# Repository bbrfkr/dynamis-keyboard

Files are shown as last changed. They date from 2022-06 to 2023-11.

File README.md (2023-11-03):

# dynamis
"dynamis" is the open-source 65% keyboard integrated with trackball.

dynamis

## concept
- upgradable
    - This keyboard can be upgraded from sandwitch mounted case to gasket mounted case.
- input only with this 
    - This keyboard is integrated with 34mm trackball, so you need only this to input!
- compact and major
    - 65% layout that is compact and major have been adopted.
- rich layout options
    - split backspace, split left and right shift, split space and iso enter are supported.

## supported key layout
supported-layout

## how to build
### Collect Parts
1. Order semi-assembled pcb by following the [gerbers](https://github.com/bbrfkr/dynamis-keyboard/tree/main/gerbers), [bom](https://github.com/bbrfkr/dynamis-keyboard/blob/main/bom.csv) and [positions](https://github.com/bbrfkr/dynamis-keyboard/blob/main/dynamis-pos.csv) files.
1. Order fr4 plate by following the [plate gerbers](https://github.com/bbrfkr/dynamis-keyboard/tree/main/plate/gerbers).
1. Order the 3d print for trackball cup by the following [stl file](https://github.com/bbrfkr/dynamis-keyboard/blob/main/trackball-cup/trackball-cup.stl) (Here, FDM print should be selected).
1. Choose case options between [sandwitch](https://github.com/bbrfkr/dynamis-keyboard/tree/main/case/sandwitch) and [3d printed](https://github.com/bbrfkr/dynamis-keyboard/tree/main/case/3dp).
1. Collect parts by following the [pcba BOM.md](https://github.com/bbrfkr/dynamis-keyboard/blob/main/BOM.md) and the each BOM.md of selected case option.

### Assemble
1. Assemble semi-assembled pcb completely by following the [pcba build guide](https://github.com/bbrfkr/dynamis-keyboard/blob/main/BUILD.md)
1. Assemble case by following the each BUILD.md of selected case option.

## flash firmware
"dynamis" supports [qmk](https://github.com/qmk/qmk_firmware/tree/master/keyboards/bbrfkr/dynamis). Therefore, you can flash firmware by using [qmk toolbox](https://github.com/qmk/qmk_toolbox).

You can download the firmware for this keyboard from [here](https://github.com/bbrfkr/dynamis-keyboard/releases).

## remap keymap
"dynamis" supports [via](https://www.caniusevia.com/). Therefore, it is recommended that you remap keymap through via. You can download the via definition from [here](https://github.com/bbrfkr/dynamis-keyboard/releases). However, w.r.t. dynamis v2, `KC_F18` and `KC_F19` is hard-coded with `increase DPI` and `decrease DPI` features.

Moreover, "dynamis" is registered in [remap](https://remap-keys.app/catalog/stOy3bAlBUlsGzHCaDIQ). From this, you can remap keymap through web browser.

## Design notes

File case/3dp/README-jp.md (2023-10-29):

# 3Dプリントトップマウントケース
- [パーツリスト](https://github.com/bbrfkr/dynamis-keyboard/blob/main/case/3dp/BOM-jp.md)
- [ビルドガイド](https://github.com/bbrfkr/dynamis-keyboard/blob/main/case/3dp/BUILD-jp.md)

dynamis

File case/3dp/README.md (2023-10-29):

# 3d printed top mount case
- [parts list](https://github.com/bbrfkr/dynamis-keyboard/blob/main/case/3dp/BOM.md)
- [build guide](https://github.com/bbrfkr/dynamis-keyboard/blob/main/case/3dp/BUILD.md)

dynamis

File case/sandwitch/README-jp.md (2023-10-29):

# サンドイッチマウントケース
- [パーツリスト](https://github.com/bbrfkr/dynamis-keyboard/blob/main/case/sandwitch/BOM-jp.md)
- [ビルドガイド](https://github.com/bbrfkr/dynamis-keyboard/blob/main/case/sandwitch/BUILD-jp.md)

dynamis

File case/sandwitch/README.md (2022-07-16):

# sandwitch mount case
- [parts list](https://github.com/bbrfkr/dynamis-keyboard/blob/main/case/sandwitch/BOM.md)
- [build guide](https://github.com/bbrfkr/dynamis-keyboard/blob/main/case/sandwitch/BUILD.md)

dynamis

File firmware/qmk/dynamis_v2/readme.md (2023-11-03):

# dynamis

## general information
dynamis

Upgradable 65% row staggered keyboard integrated a trackball

* Keyboard Maintainer: [bbrfkr](https://github.com/bbrfkr/)
* Hardware Supported: dynamis PCBs
* Hardware Availability: https://github.com/bbrfkr/dynamis-keyboard

## bootloader

Enter the bootloader in 2 ways:

* **Physical reset button**: Briefly press the button on the back of the PCB - some may have pads you must short instead
* **Keycode in layout**: Press the key mapped to `QK_BOOT` if it is available

## build and flash firmware

Make example for this keyboard (after setting up your build environment):

    make bbrfkr/dynamis_v2:default

Flashing example for this keyboard:

    make bbrfkr/dynamis_v2:default:flash

See the [build environment setup](https://docs.qmk.fm/#/getting_started_build_tools) and the [make instructions](https://docs.qmk.fm/#/getting_started_make_guide) for more information. Brand new to QMK? Start with our [Complete Newbs Guide](https://docs.qmk.fm/#/newbs).

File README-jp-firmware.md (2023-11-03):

## ファームウェアの書き込み
「dynamis」は[qmk](https://github.com/qmk/qmk_firmware/tree/main/keyboards/bbrfkr/dynamis)を用いたファームウェアに対応しています。 したがって、[qmk toolbox](https://github.com/qmk/qmk_toolbox)などを利用してファームウェアを書き込むことができます。ここではqmk toolboxを利用したファームウェアの書き込みについて説明します。

まず、ファームウェアをダウンロードします。[こちら](https://github.com/bbrfkr/dynamis-keyboard/releases)から、最新のvia対応ファームウェア `bbrfkr_dynamis_via.hex` をダウンロードします。

次にqmk toolboxの最新バージョンを[こちら](https://github.com/qmk/qmk_toolbox/releases)からダウンロードし、インストールします。

qmk toolboxを起動すると、次のような画面が表示されます。

qmk_toolbox_01

`Open` をクリックして、ダウンロードしたファームウェアを選択します。

qmk_toolbox_02

キーボードのPCBAにあるリセットスイッチを押すか、 `Reset` に対応したキーを押します。すると、右上の `Flash` というボタンと左下の `Clear EEPROM` というボタンが押せるようになります。

ファームウェアを書き込むには `Flash` を押します。 `Flash` を押す前に `Clear EEPROM` を押しておくと、現在のキーマップが初期化されますので、必要に応じてこちらも押してください。

qmk_toolbox_03

`Validation... Success` まで表示されれば、ファームウェアの書き込みは完了になります。

qmk_toolbox_04

## キーマップの書き換え
「dynamis」は [via](https://www.caniusevia.com/)をサポートしています。 よって、viaを介してキーマップを書き換えることを推奨します。さらに、「dynamis」は[remap](https://remap-keys.app/catalog/stOy3bAlBUlsGzHCaDIQ)に登録されているため、Webブラウザ上からキーマップを書き換えることもできます。

ここではviaを使ったキーマップの書き換えについて説明します。

まず、[こちら](https://usevia.app/#/)にアクセスします。ブラウザに次のような画面が表示されたら、 `Authorize device` ボタンをクリックします。

via_01

するとブラウザからHIDデバイスとしてdynamisの接続を許可するか、確認が求められますので、 `dynamis` を選択して許可します。以下はChromeの例です。

via_02

接続許可が成功すると以下の画面に遷移します。

via_03

キーマップを変更するには、変更したいキーをクリックした後、下に表示されたキー群から目的のキーをクリックします。特にキーボードを再接続等しなくても、すぐに変更は反映されます。

また、スプリットライトシフトやISOエンターなどの、キーレイアウト自体を変更したい場合は、先に左の欄にある `LAYOUTS` をクリックします。すると次のような表示になります。

via_04

下に表示された、必要なキーレイアウトのスイッチのON・OFFを切り替えます。切り替えたら、目的通りか上のキーレイアウトを見て確認してください。

via_05

ロータリエンコーダの挙動を変えたいときは、ロータリエンコーダ部分をクリックして、下部に表示されるエントリを修正します。

via_06

`Rotate Clockwise` が時計回りの挙動、 `Rotate Counterclockwise` が反時計回りの挙動に対応します。エントリの修正時にはqmkの任意のキーコードを入力できます。qmkのキーコードは[こちら](https://github.com/qmk/qmk_firmware/blob/master/docs/keycodes.md)から検索できます。

ただし、dynamis v2においてはqmkのキーコード `KC_F18` と `KC_F19` に対してそれぞれトラックボールの `DPI増加` および `DPI減少` にハードコーディングされています。

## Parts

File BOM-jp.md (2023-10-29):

# PCBA - パーツリスト
|名称|数量|説明|
|---|---|---|
|PCBA(半完成品)|1|[ガーバーファイル](https://github.com/bbrfkr/dynamis-keyboard/tree/main/gerbers)と[BOMリスト](https://github.com/bbrfkr/dynamis-keyboard/tree/main/bom.csv)、[ポジションファイル](https://github.com/bbrfkr/dynamis-keyboard/tree/main/dynamis-pos.csv)にしたがって注文してください|
|スイッチソケット|76|MX互換品がサポートされています|
|LED|5|SK6812MINI-Eがサポートされています|
|トラックボールカップベース|1|[こちら](https://github.com/bbrfkr/dynamis-keyboard/blob/main/trackball-cup/trackball-cup.stl)をFDM 3Dプリントしてください|
|セラミックボール 2mm|3|トラックボールの支持用|
|M2ヒートインサート|4|長さ3mm|
|M2なべネジ|4|長さ4mm|
|ロータリエンコーダ|1|例えば、[EC12E24404A6](https://www.mouser.jp/datasheet/2/15/EC12E-1370769.pdf)など|
|トラックボールセンサ（ミラー付き）|1|[PMW3360DM-T2QU](https://d3s5r33r268y59.cloudfront.net/datasheets/9604/2017-05-07-18-19-11/PMS0058-PMW3360DM-T2QU-DS-R1.50-26092016._20161202173741.pdf)がサポートされています|
|エンコーダ用ノブ|1|-|
|PCBマウント式のスタビライザ|(必要数)|MX互換品がサポートされています|

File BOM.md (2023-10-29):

# parts list for pcba

|name|qty|description|
|---|---|---|
|dynamis pcba(semi-assembled)|1|Order by the following [gerbers](https://github.com/bbrfkr/dynamis-keyboard/tree/main/gerbers), [bom](https://github.com/bbrfkr/dynamis-keyboard/tree/main/bom.csv) and [position](https://github.com/bbrfkr/dynamis-keyboard/tree/main/dynamis-pos.csv) files|
|switch socket|76|MX compatible one is supported|
|LED|5|SK6812MINI-E is supported|
|trackball cup base|1|FDM 3d printed by [this stl](https://github.com/bbrfkr/dynamis-keyboard/blob/main/trackball-cup/trackball-cup.stl)|
|ceramic ball 2mm|3|For supporting trackball|
|M2 heat insert|4|The length is 3mm|
|M2 pan head screw|4|The length is 4mm|
|rotary encoder|1|e.g. [EC12E24404A6](https://www.mouser.jp/datasheet/2/15/EC12E-1370769.pdf)|
|trackball sensor (with mirror)|1|[PMW3360DM-T2QU](https://d3s5r33r268y59.cloudfront.net/datasheets/9604/2017-05-07-18-19-11/PMS0058-PMW3360DM-T2QU-DS-R1.50-26092016._20161202173741.pdf) is supported|
|encoder knob|1|-|
|pcb mounted stabilizer|(qty you need)|MX compatible one is supported|

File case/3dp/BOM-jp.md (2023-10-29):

# 3Dプリントケース - パーツリスト
|名称|数量|説明|
|---|---|---|
|3Dプリントボトムケース|1|[こちら](https://github.com/bbrfkr/dynamis-keyboard/blob/main/case/3dp/top-mount-case-bottom_case.stl)をFDM 3Dプリントしてください|
|3Dプリントトップケース|1|[こちら](https://github.com/bbrfkr/dynamis-keyboard/blob/main/case/3dp/top-mount-case-top_case.stl)をFDM 3Dプリントしてください|
|ブラスウェイト|1|オプション。[こちら](https://github.com/bbrfkr/dynamis-keyboard/blob/main/case/3dp/top-mount-case-weight.stl)をCNC処理等してください|
|ケースフォーム|1|オプション。厚さ2mmで[こちら](https://github.com/bbrfkr/dynamis-keyboard/blob/main/case/3dp/case-foam.svg)をレーザーカットしてください|
|PCBA|1|[こちら](https://github.com/bbrfkr/dynamis-keyboard/blob/main/BUILD-jp.md)でビルドされたもの|
|バッジ|1|[こちらのフォルダ](https://github.com/bbrfkr/dynamis-keyboard/tree/main/case/3dp/badge)から好きなSTLファイルを選択し、透明レジンによる光造形3Dプリントを行ってください|
|FR4プレート|1|-|
|キーキャップ|(必要数)|MX互換品をサポートしています|
|M2ヒートインサート|12|長さ3mm|
|M2なべネジ|10|長さ4mm|
|M2皿ネジ|2|長さ4mm|
|M3ヒートインサート|10(ブラスウェイトを使う場合、14)|長さ3mm|
|M3なべネジ|10|長さ10mm|
|M3皿ネジ|4|オプション。ブラスウェイト用。長さ6mm|
|プレートフォーム|1|オプション。厚さ3.5mmで[こちら](https://github.com/bbrfkr/dynamis-keyboard/blob/main/case/3dp/plate-foam.svg)をレーザーカットしてください|
|ゴム足|4|-|
|キースイッチ|(必要数)|MX互換品をサポートしています|
|トラックボール|1|直径34mm|

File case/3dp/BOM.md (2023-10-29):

# parts list for 3d printed case
|name|qty|description|
|---|---|---|
|3d printed bottom case|1|FDM 3d printed by [this stl](https://github.com/bbrfkr/dynamis-keyboard/blob/main/case/3dp/top-mount-case-bottom_case.stl)|
|3d printed top case|1|FDM 3d printed by [this stl](https://github.com/bbrfkr/dynamis-keyboard/blob/main/case/3dp/top-mount-case-top_case.stl)|
|brass weight|1|Option. CNC process etc with [this stl](https://github.com/bbrfkr/dynamis-keyboard/blob/main/case/3dp/top-mount-case-weight.stl)|
|case foam|1|Option. The thickness is 2mm. Laser cut with [this svg](https://github.com/bbrfkr/dynamis-keyboard/blob/main/case/3dp/case-foam.svg)|
|dynamis pcba|1|The one is build at [here](https://github.com/bbrfkr/dynamis-keyboard/blob/main/BUILD.md)|
|dynamis badge|1|Transparent resin printed. Selected from [this folder](https://github.com/bbrfkr/dynamis-keyboard/tree/main/case/3dp/badge)|
|fr4 plate|1|Order by the following [gerbers](https://github.com/bbrfkr/dynamis-keyboard/tree/main/plate/gerbers)|
|keycap|(qty you need)|MX compatible one is supported|
|M2 heat insert|12|The length is 3mm|
|M2 pan head screw|10|The length is 4mm|
|M2 countersunk screw|2|The length is 4mm|
|M3 heat insert|10(14 If you need a brass weight)|The length is 3mm|
|M3 pan head screw|10|The length is 10mm|
|M3 countersunk screw|4|Option. For brass weight. The length is 6mm|
|plate foam|1|Option. The thickness is 3.5mm. Laser cut with [this svg](https://github.com/bbrfkr/dynamis-keyboard/blob/main/case/3dp/plate-foam.svg)|
|rubber foot|4|-|
|switch|(qty you need)|MX compatible one is supported|
|trackball|1|The diameter is 34mm|

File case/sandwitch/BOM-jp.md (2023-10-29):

# サンドイッチケース - パーツリスト
|名称|数量|説明|
|---|---|---|
|PCBA|1|[こちら](https://github.com/bbrfkr/dynamis-keyboard/blob/main/BUILD-jp.md)でビルドされたもの|
|FR4プレート|1|[ガーバーファイル](https://github.com/bbrfkr/dynamis-keyboard/tree/main/plate/gerbers)にしたがって注文してください|
|FR4ボトムプレート|1|[ガーバーファイル](https://github.com/bbrfkr/dynamis-keyboard/tree/main/case/sandwitch/gerbers)にしたがって注文してください|
|キーキャップ|(必要数)|MX互換品をサポートしています|
|M2なべネジ|28|長さ4mm|
|M2両雌ネジスペーサー|14|長さ9mm|
|ゴム足|4|高さ2mm以上|
|キースイッチ|(必要数)|MX互換品をサポートしています|
|トラックボール|1|直径34mm|

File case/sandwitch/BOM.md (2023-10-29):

# parts list for sandwitch case
|name|qty|description|
|---|---|---|
|dynamis pcba|1|The one is build at [here](https://github.com/bbrfkr/dynamis-keyboard/blob/main/BUILD.md)|
|fr4 plate|1|Order by the following [gerbers](https://github.com/bbrfkr/dynamis-keyboard/tree/main/plate/gerbers)|
|fr4 bottom plate|1|Order by the following [gerbers](https://github.com/bbrfkr/dynamis-keyboard/tree/main/case/sandwitch/gerbers)|
|keycap|(qty you need)|MX compatible one is supported|
|M2 pan head screw|28|The length is 4mm|
|M2 spacer|14|The length is 9mm|
|rubber foot|4|The height is greater than 2mm|
|switch|(qty you need)|MX compatible one is supported|
|trackball|1|The diameter is 34mm|

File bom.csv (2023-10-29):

Comment | Designator | Footprint | LCSC
22pF | C0,C1 | Capacitor_SMD:C_1206_3216Metric | C107174
1μF | C2,C14,C18 | Capacitor_SMD:C_1206_3216Metric | C1848
0.1μF | C3,C4,C5,C8,C9,C11,C13,C15,C17,C19 | Capacitor_SMD:C_1206_3216Metric | C24497
10μF | C6,C10,C12,C16,C20 | Capacitor_SMD:C_1206_3216Metric | C13585
4.7μF | C7,C21 | Capacitor_SMD:C_1206_3216Metric | C29823
D | D00_00,D00_01,D00_02,D00_03,D00_04,D00_05,D00_06,D01_00,D01_01,D01_02,D01_03,D01_04,D01_05,D01_06,D02_00,D02_01,D02_02,D02_03,D02_04,D02_05,D02_06,D03_00,D03_01,D03_02,D03_03,D03_04,D03_05,D03_06,D04_00,D04_01,D04_02,D04_03,D04_04,D04_05,D04_06,D05_00,D05_01,D05_02,D05_03,D05_04,D05_05,D05_06,D06_00,D06_01,D06_02,D06_03,D06_04,D06_05,D06_06,D07_00,D07_01,D07_02,D07_03,D07_04,D07_05,D07_06,D08_00,D08_01,D08_02,D08_03,D08_04,D08_05,D08_06,D09_00,D09_01,D09_02,D09_03,D09_04,D09_05,D09_06 | random-keyboard-parts:D_SOD-123-Pretty | C81598
ESD5Z5V0 | ESDD0 | Diode_SMD:D_SOD-523 | C502546
SMD0805-050-16V | F0 | Fuse:Fuse_1206_3216Metric | C2833485
USB_C_Receptacle_USB2.0 | J0 | Connector_USB:USB_C_Receptacle_HRO_TYPE-C-31-M-12 | C165948
22 | R0,R1 | Resistor_SMD:R_1206_3216Metric | C17958
63.4K | R10 | Resistor_SMD:R_1206_3216Metric | C45027
52.3k | R11 | Resistor_SMD:R_1206_3216Metric | C247238
30.1k | R12 | Resistor_SMD:R_1206_3216Metric | C425547
1M | R13 | Resistor_SMD:R_1206_3216Metric | C17927
10k | R2,R5,R6 | Resistor_SMD:R_1206_3216Metric | C17928
5.1k | R3,R4 | Resistor_SMD:R_1206_3216Metric | C964991
39 | R7 | Resistor_SMD:R_1206_3216Metric | C286655
37.4k | R9 | Resistor_SMD:R_1206_3216Metric | C247280
TS-1187A-B-A-B | RESET_SW0 | TS-1187A-B-A-B:SW_TS-1187A-B-A-B | C318884
ATmega32U4-M | U0 | Package_DFN_QFN:QFN-44-1EP_7x7mm_P0.5mm_EP5.2x5.2mm | C112161
TPS73601DBV | U2,U3 | Package_TO_SOT_SMD:SOT-23-5 | C59200
TPD4E05U06DQAR | U4 | TPD4E05U06DQAR:USON-10_L2.5-W1.0-P0.50-BL | C2836386
16Mhz | Y0 | X322516MLB4SI:OSC-SMD_4P-L3.2-W2.5-BL | C13738

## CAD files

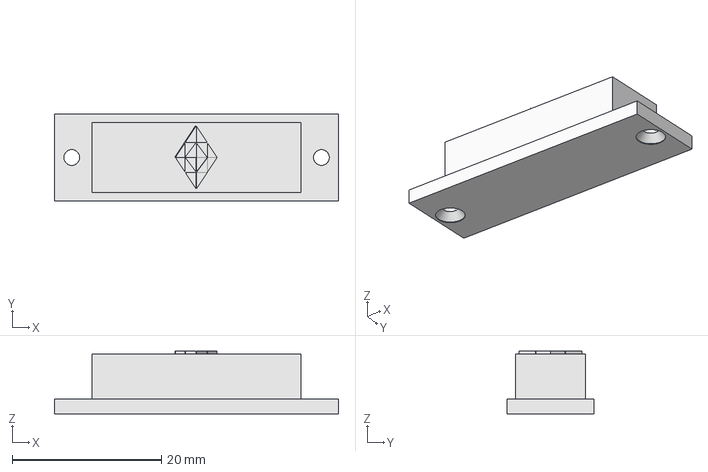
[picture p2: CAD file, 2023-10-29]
case/3dp/badge/badges.FCStd
38.1 x 11.7 x 8.40 mm

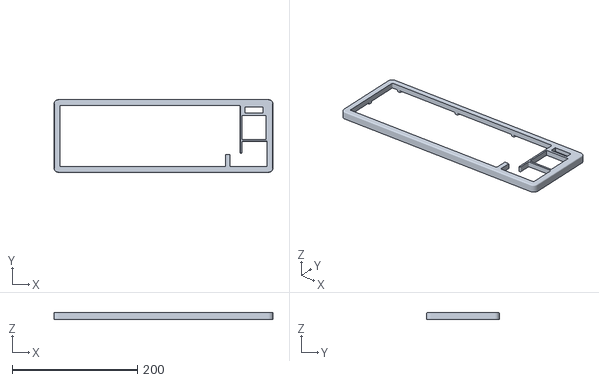
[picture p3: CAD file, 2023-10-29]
case/3dp/top-mount-case-top_case.stl
349.5 x 116.2 x 11.4

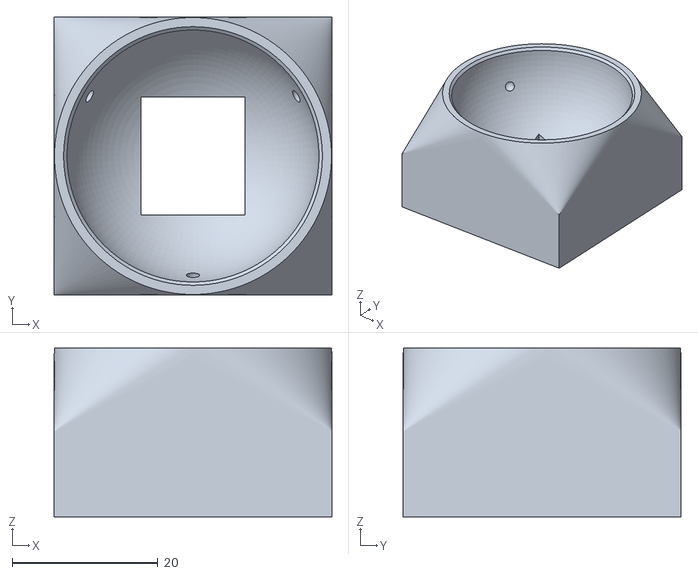
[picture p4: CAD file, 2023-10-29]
trackball-cup/trackball-cup.stl
38.1 x 38.1 x 23.1

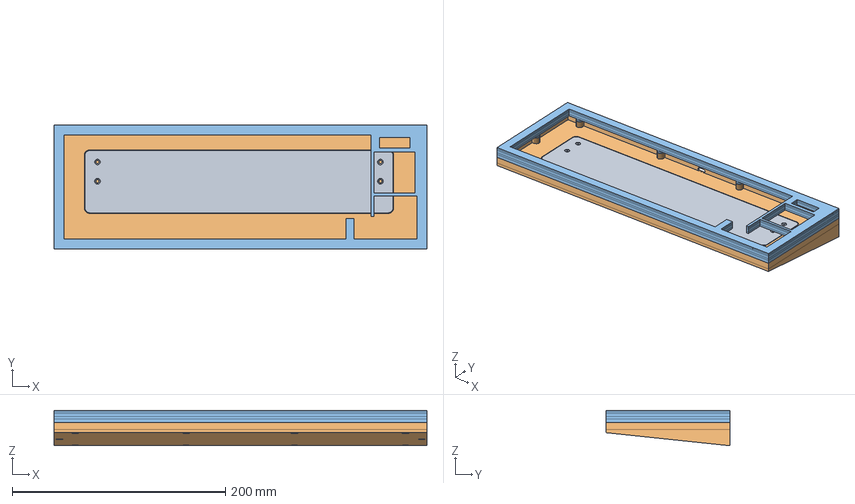
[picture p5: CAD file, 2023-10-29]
case/3dp/top-mount-case.FCStd
349.6 x 116.3 x 33.2 mm
weight
bottom_case
top_case

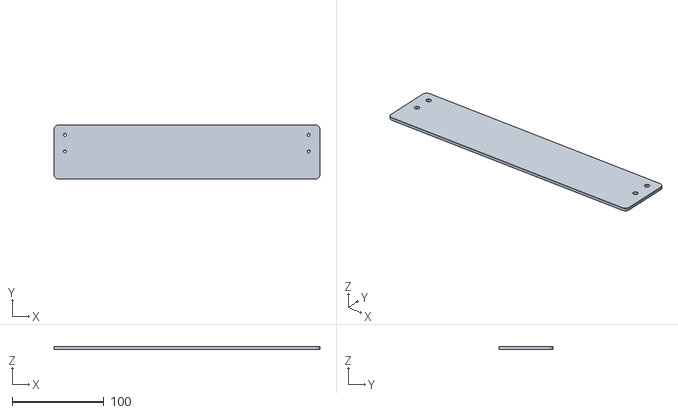
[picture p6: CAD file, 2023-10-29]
case/3dp/top-mount-case-weight.stl
289.4 x 58.9 x 3.00

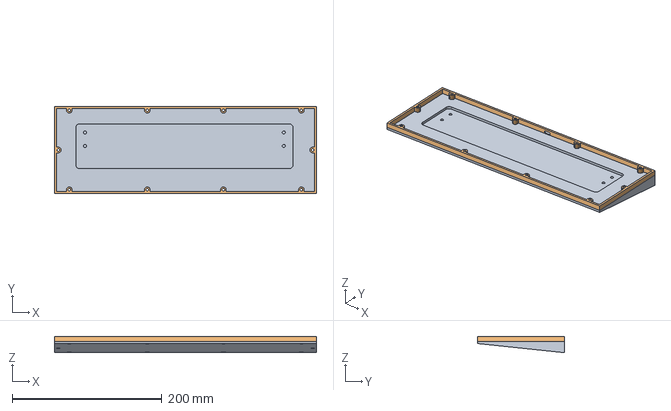
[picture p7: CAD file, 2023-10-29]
case/3dp/top-mount-case-bottom_case.step
349.6 x 116.3 x 21.8 mm

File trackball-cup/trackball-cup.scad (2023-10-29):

// カップ穴の直径
sphere_size = 34.6;

// カップケースの谷の裾幅
bottom_offset = 7.5;

// ミラーの厚さ
mirror_thin = 3.4;

// ミラーからカップ穴までのオフセット
mirror_offset = 0.8;

// 台座の厚さ
support_thin = 11.7;

// 台座の一片の長さ
support_length = 38.1;

$fn = 64;

module ball_cup(){
    difference(){
        // ベース
        hull(){
            difference(){
                union(){
                    translate([0,0,mirror_thin+mirror_offset+sphere_size/2]) {
                        sphere(sphere_size/2 + (support_length - sphere_size)/2);
                    }
                    cylinder(
                        h=mirror_thin+mirror_offset+sphere_size/2,
                        r1=sphere_size/2 + (support_length - sphere_size)/2,
                        r2=sphere_size/2 + (support_length - sphere_size)/2
                    );
                }
                // カップ穴の3/5の位置でぶった切る
                translate([0,0,mirror_thin+mirror_offset+ 70 * sphere_size/128]) cylinder(h=9999, r1=9999, r2=9999);
            }
            translate([0,0, support_thin/2]) cube([support_length, support_length, support_thin], center=true);
        }

        // カップ穴
        translate([0,0,mirror_thin+mirror_offset+sphere_size/2]) sphere(sphere_size/2);

        // ビーズ用穴 (2mm)
        translate([0,0,mirror_thin+mirror_offset]) {
            rotate(0){
                translate([0, -62.25 * (sphere_size)/128, sphere_size/3]){
                    sphere(1.05);
                }
            }
            rotate(120){
                translate([0, -62.25 * (sphere_size)/128, sphere_size/3]){
                    sphere(1.05);
                }
            }
            rotate(240){
                translate([0, -62.25 * (sphere_size)/128, sphere_size/3]){
                    sphere(1.05);
                }
            }
        }            
 
        // インサートナット用穴
            translate([16, -16, -0.1]){
                cylinder(h=4.1, r1=1.5, r2=1.5);
            }
            translate([16, 16, -0.1]){
                cylinder(h=4.1, r1=1.5, r2=1.5);
            }
            translate([-16, -16, -0.1]){
                cylinder(h=4.1, r1=1.5, r2=1.5);
            }
            translate([-16, 16, -0.1]){
                cylinder(h=4.1, r1=1.5, r2=1.5);
            }
        //ミラー用穴
        rotate(90){
            cube([22.5,20,mirror_thin*2], center=true);
        }
        rotate(90){
            cube([16.2,14.2,999], center=true);
        }
    } 
}

ball_cup();

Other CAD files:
case/3dp/badge/logo_badge.stl
case/3dp/badge/logo_with_name_badge.stl
case/3dp/top-mount-case-bottom_case.f3d
case/3dp/top-mount-case-bottom_case.stl
case/3dp/top-mount-case-top_case.f3d

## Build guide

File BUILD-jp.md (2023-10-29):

# ビルドガイド for PCBA(PCB-Assembly)
1. 部品を用意します。
    pcba01
1. LEDをはんだ付けします。 LEDの欠けた足がPCB上の白い点に近いパッドに乗るようにしてください。
    pcba02
    pcba03
1. 少量のはんだをスイッチソケットのパッドすべてに乗せます。
    pcba04
1. スイッチソケットをはんだ付けします。片側のパッドだけすべてはんだ付けし、そのあとにもう片方をはんだ付けすると多少楽になります。
    pcba05
1. トラックボールセンサをレンズがスペースキーを向くように、PCBの裏側から差し込みます。そうしたらすべてのピンをはんだ付けします。
    pcba06
    pcba07
1. ロータリエンコーダを配置し、はんだ付けします。
    pcba08
    pcba09
1. ノブをおいて、ねじを締めます。
    pcba10
1. トラックボールカップについている三つのくぼみに2mmセラミックボールを配置して、押し込みます。トラックボールで軽く押し込むようにするとしっかり入ります。
    pcba11
    pcba12
1. トラックボールの底面四隅の穴に、ヒートインサートをはんだごてで圧入します。
    pcba13
    pcba14
1. センサミラーをトラックボールセンサの上に乗せます。
    pcba15
1. センサミラーを覆うようにトラックボールカップを取り付け、PCB裏側からM2ねじでねじ止めします。
    pcba16
    pcba17
1. 写真と見比べて、作業内容を確認してください。
    pcba18
    pcba19
1. 最後に、PCBマウント方式のスタビライザを取り付けて完了です。
    pcba20

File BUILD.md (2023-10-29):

# build guide for pcba
1. Prepare the parts.
    pcba01
1. Solder leds. Put the cut-off leg of led at the pad with a white dot.
    pcba02
    pcba03
1. Put a little solder on the pads for switch sockets.
    pcba04
1. Solder switch sockets.
    pcba05
1. Put trackball sensor at the bottom of pcb such as the lens faces the direction of space key, and solder it.
    pcba06
    pcba07
1. Put rotary encoder, and solder it.
    pcba08
    pcba09
1. Put and screw knob to encoder.
    pcba10
1. Put and push ceramic balls to three caves of trackball cup.
    pcba11
    pcba12
1. Push heat insert into the hole with the bottom of trackball cup by the solder iron.
    pcba13
    pcba14
1. Put sensor mirror to trackball sensor.
    pcba15
1. Cover sensor mirror with trackball cup. Then, screw trackball cup from the bottom of pcb.
    pcba16
    pcba17
1. Check your work.
    pcba18
    pcba19
1. Finally, put your favorite pcb-mounted stabs.
    pcba20

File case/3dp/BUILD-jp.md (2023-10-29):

# 3Dプリントケース - ビルドガイド
1. ボトムケース用のパーツを用意します。
    3d-printed-01

1. (オプション) M3ヒートインサートを4つ、ブラスウェイト用に作られたスペースにある4つの穴に取り付けます。
    3d-printed-02

1. (オプション) M3皿ネジでブラスウエイトを取り付けます。
    3d-printed-03

1. ゴム足を取り付けます。
    3d-printed-04

1. トップケース用のパーツを用意します。
    3d-printed-05
    3d-printed-06

1. M2ヒートインサートを2つ、バッジ用に作られたスペースにある2つの穴に取り付けます。
    3d-printed-07

1. M2皿ネジでバッジを取り付けます。
    3d-printed-08

1. M2ヒートインサートを10個、トップケースの10個の専用穴に取り付けます。
    3d-printed-09

1. FR4プレートをM2なべネジで取り付けます。
    3d-printed-10

1. M3ヒートインサートを10個、トップケースの10個の専用穴に取り付けます。
    3d-printed-11

1. トップパーツとプレートフォーム(オプション)、PCBAを用意します。
    3d-printed-12

1. (オプション) PCBAにプレートフォームを置きます。
    3d-printed-13

1. PCBAにトップパーツを置きます。
    3d-printed-14

1. キースイッチを取り付けます。
    3d-printed-15

1. トップパーツとケースフォーム(オプション)、ボトムパーツを用意します。
    3d-printed-16

1. (オプション) ボトムパーツにケースフォームを置きます。
    3d-printed-17

1. M3なべネジでボトムパーツの穴からトップパーツをネジ止めします。
    3d-printed-18

1. キーキャップとトラックボールを取り付けます
    3d-printed-19

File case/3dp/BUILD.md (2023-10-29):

# build guide for 3d printed case
1. Prepare parts for bottom part.
    3d-printed-01

1. (Option) Install 4 M3 heat inserts to the 4 holes at the space of brass weight.
    3d-printed-02

1. (Option) Screw a brass weight with M3 countersunk screws.
    3d-printed-03

1. Affix rubber feet.
    3d-printed-04

1. Prepare parts for top part.
    3d-printed-05
    3d-printed-06

1. Install 2 M2 heat inserts to the 2 holes at the space of badge.
    3d-printed-07

1. Screw a badge with M2 countersunk screws.
    3d-printed-08

1. Install 10 M2 heat inserts to the 10 holes of top case.
    3d-printed-09

1. Screw the fr4 plate with M2 pan head screws.
    3d-printed-10

1. Install 10 M3 heat inserts to the 10 holes of top case.
    3d-printed-11

1. Prepare top part, plate foam(Option) and pcba.
    3d-printed-12

1. (Option) Put plate foam on pcba.
    3d-printed-13

1. Put top part on pcba.
    3d-printed-14

1. Install switches.
    3d-printed-15

1. Prepare top part, case foam(Option) and bottom part.
    3d-printed-16

1. (Option) Put case foam on pcba.
    3d-printed-17

1. Screw bottom part to top part with M3 screws through the holes of bottom part.
    3d-printed-18

1. Install keycaps and trackball.
    3d-printed-19

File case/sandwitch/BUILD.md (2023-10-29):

# build guide for sandwitch case
1. Prepare parts for bottom part.
    sandwitch-01

1. Install 9mm spacers to bottom plate with M2 pan head screws. Here, It is checked that the spacers aren't at the side of plate with dynamis logo.
    sandwitch-02

1. Affix rubber feet to the side of plate with dynamis logo.
    sandwitch-03

1. Prepare parts for top part.
    sandwitch-04

1. Put switch plate on pcba.
    sandwitch-05

1. Install switches.
    sandwitch-06

1. Prepare top part and bottom part.
    sandwitch-07

1. Put top part on bottom part and screw top part with M2 pan head screws.
    sandwitch-08

1. Install keycaps and trackball.
    sandwitch-09

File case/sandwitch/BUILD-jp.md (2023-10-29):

# サンドイッチケース - ビルドガイド
1. ボトムケース用のパーツを用意します。
    sandwitch-01

1. 9mmスペーサーをM2なべネジでボトムプレートに取り付けます。このとき、スペーサーがプレートのロゴのない方に取り付けられていることを確認してください。
    sandwitch-02

1. ゴム足をボトムプレートのロゴがある方に取り付けます。
    sandwitch-03

1. トップケース用のパーツを用意します。
    sandwitch-04

1. PCBAにスイッチプレートを重ねます。
    sandwitch-05

1. キースイッチを取り付けます。
    sandwitch-06

1. ボトムケースとトップケースを用意します。
    sandwitch-07

1. トップケースをボトムケースに重ね、M2なべネジでネジ止めします。
    sandwitch-08

1. キーキャップとトラックボールを取り付けます。
    sandwitch-09

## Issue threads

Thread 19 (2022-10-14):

mount方式をtop mountに修正する

bbrfkr, 2022-10-14:
キーボードを打鍵するときに気にしていることとして打鍵音があるが、gasket mountを採用した時の打鍵音への影響が感じられず、どちらかというとfoamで完全にスペースが埋まっているかの方が影響が大きいと感じた。

そこで、gasket mountの採用を取りやめてtop mountを採用し、gasketを制作するコストと実装するコストを削減したい。また可能ならば、キーボードサイズもコンパクトにできれば理想。

bbrfkr, 2022-10-14:
top mountへ修正するコストの方が高くつく & キーボードサイズはむしろ大きくなるので、取りやめ。

Closed 2022-10-14.

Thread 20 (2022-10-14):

eva foamを2mmに統一する

bbrfkr, 2022-10-14:
gasket、plate foam、case foamを一律2mmのevaおよびその重ね合わせで統一する。

gasket: 2mm 粘着付き
plate foam: 2mm + 2mm
case foam: 2mm ソケット穴付き + 2mm

bbrfkr, 2022-10-15:
修正済み。close

Closed 2022-10-15.

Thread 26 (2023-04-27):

develop version 2.0.0

bbrfkr, 2023-04-27:
# Plan
- remove acrylic case
- replace gasket mount 3dp case to top mount 3dp case
- replace underglow led to backlight led
- centering usb connector
- remapping curcuit
- improve trackball movement more smoothly

bbrfkr, 2023-10-29:
merged.

Closed 2023-10-29.

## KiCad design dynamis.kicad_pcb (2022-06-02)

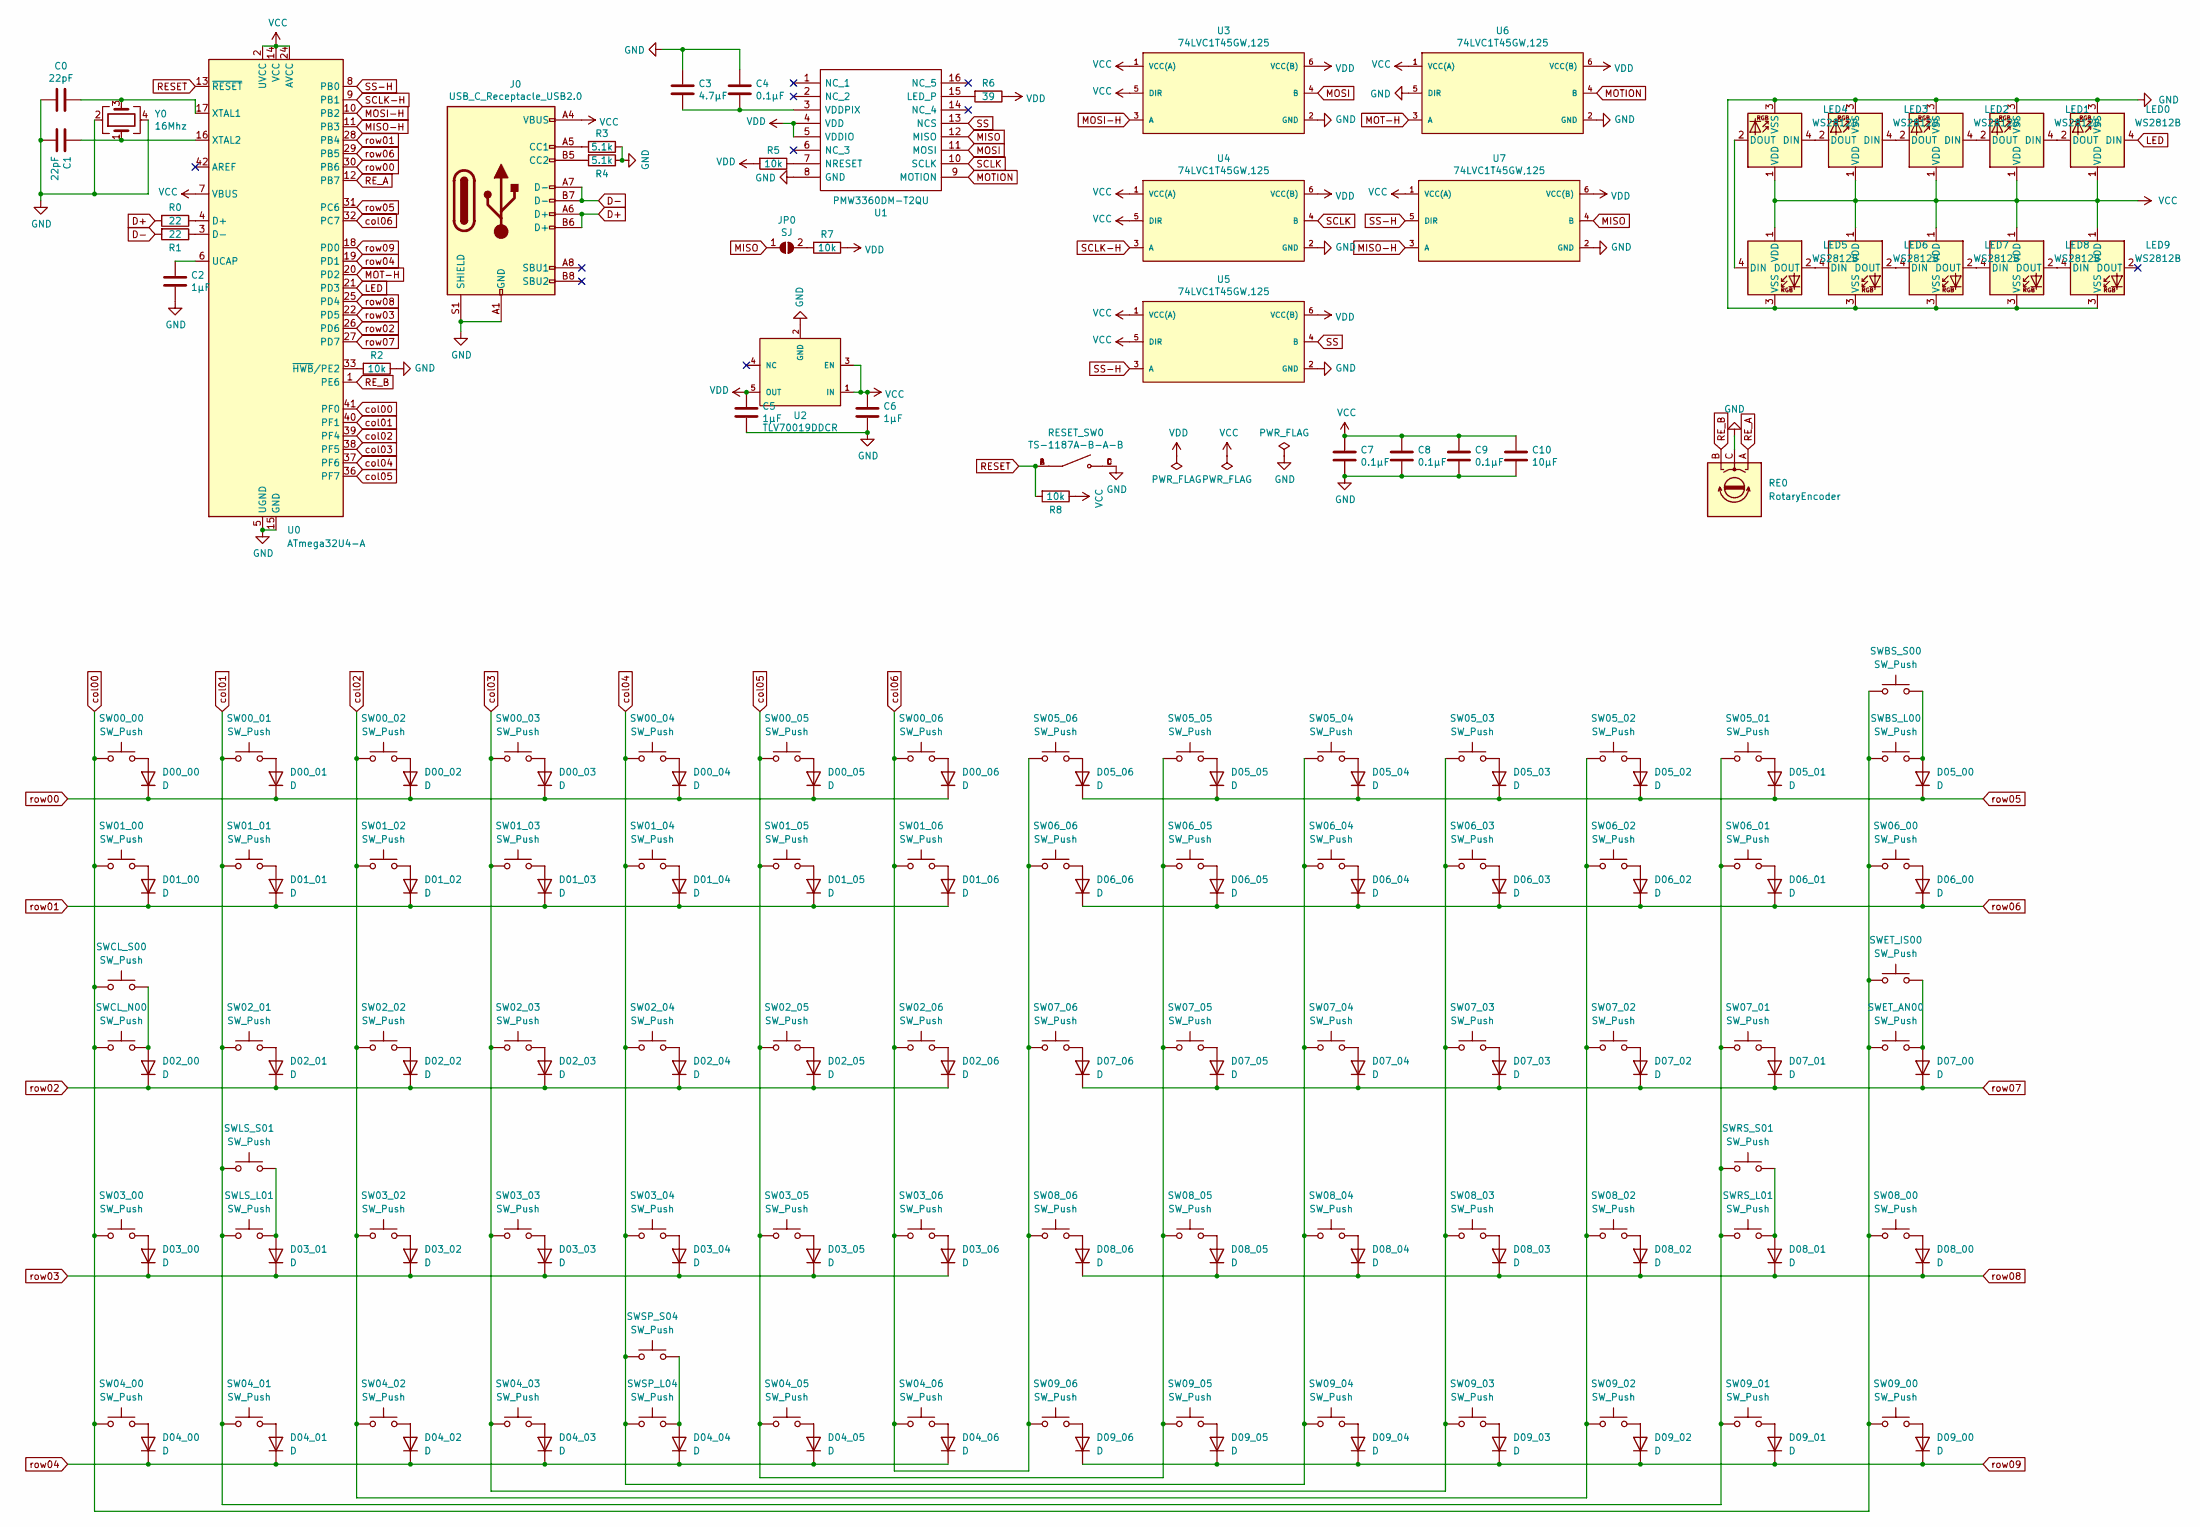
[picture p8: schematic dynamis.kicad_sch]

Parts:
C0, C1: 22pF; C_1206_3216Metric
C2, C5, C6: 1μF; C_1206_3216Metric
C3: 4.7μF; C_1206_3216Metric
C4, C7, C8, C9: 0.1μF; C_1206_3216Metric
C10: 10μF; C_1206_3216Metric
D00_00, D00_01, D00_02, D00_03, D00_04, D00_05, D00_06, D01_00, D01_01, D01_02, D01_03, D01_04, D01_05, D01_06, D02_00, D02_01, D02_02, D02_03, D02_04, D02_05, D02_06, D03_00, D03_01, D03_02, D03_03, D03_04, D03_05, D03_06, D04_00, D04_01, D04_02, D04_03, D04_04, D04_05, D04_06, D05_00, D05_01, D05_02, D05_03, D05_04, D05_05, D05_06, D06_00, D06_01, D06_02, D06_03, D06_04, D06_05, D06_06, D07_00, D07_01, D07_02, D07_03, D07_04, D07_05, D07_06, D08_00, D08_01, D08_02, D08_03, D08_04, D08_05, D08_06, D09_00, D09_01, D09_02, D09_03, D09_04, D09_05, D09_06: D; D_SOD-123-Pretty
J0: USB_C_Receptacle_USB2.0; USB_C_Receptacle_HRO_TYPE-C-31-M-12
JP0: SJ; SolderJumper-2_P1.3mm_Open_Pad1.0x1.5mm
LED0, LED1, LED2, LED3, LED4, LED5, LED6, LED7, LED8, LED9: WS2812B; LED_WS2812B_PLCC4_5.0x5.0mm_P3.2mm
R0, R1: 22; R_1206_3216Metric
R2, R5, R7, R8: 10k; R_1206_3216Metric
R3, R4: 5.1k; R_1206_3216Metric
R6: 39; R_1206_3216Metric
RE0: RotaryEncoder; RotaryEncoder_Alps_EC12E_Vertical_H20mm
RESET_SW0: TS-1187A-B-A-B; SW_TS-1187A-B-A-B; PARTREV A0
SW00_00, SW00_01, SW00_02, SW00_03, SW00_04, SW00_05, SW00_06, SW01_00, SW01_01, SW01_02, SW01_03, SW01_04, SW01_05, SW01_06, SW02_01, SW02_02, SW02_03, SW02_04, SW02_05, SW02_06, SW03_00, SW03_02, SW03_03, SW03_04, SW03_05, SW03_06, SW04_00, SW04_01, SW04_02, SW04_03, SW04_05, SW04_06, SW05_01, SW05_02, SW05_03, SW05_04, SW05_05, SW05_06, SW06_00, SW06_01, SW06_02, SW06_03, SW06_04, SW06_05, SW06_06, SW07_01, SW07_02, SW07_03, SW07_04, SW07_05, SW07_06, SW08_00, SW08_02, SW08_03, SW08_04, SW08_05, SW08_06, SW09_00, SW09_01, SW09_02, SW09_03, SW09_04, SW09_05, SW09_06: SW_Push; MXOnly-1U-Hotswap
SWBS_L00: SW_Push; MXOnly-1U-Hotswap
SWBS_S00: SW_Push; MXOnly-1U-Hotswap
SWCL_N00: SW_Push; MXOnly-1U-Hotswap
SWCL_S00: SW_Push; MXOnly-1U-Hotswap
SWET_AN00: SW_Push; MXOnly-1U-Hotswap
SWET_IS00: SW_Push; MXOnly-1U-Hotswap
SWLS_L01: SW_Push; MXOnly-1U-Hotswap
SWLS_S01: SW_Push; MXOnly-1U-Hotswap
SWRS_L01: SW_Push; MXOnly-1U-Hotswap
SWRS_S01: SW_Push; MXOnly-1U-Hotswap
SWSP_L04: SW_Push; MXOnly-1U-Hotswap
SWSP_S04: SW_Push; MXOnly-1U-Hotswap
U0: ATmega32U4-A; TQFP-44_10x10mm_P0.8mm
U1: PMW3360DM-T2QU; PMW3360; Manufacturer_Part_Number PMW3360DM-T2QU
U2: TLV70019DDCR; Texas_Instruments-TLV70019DDCR-Level_A
U3, U4, U5, U6, U7: 74LVC1T45GW,125; Nexperia-SOT363-11_2018-0-IPC_A; mouser part number 771-74LVC1T45GW125; digikey description IC TRNSLTR BIDIRECTIONAL 6TSSOP
Y0: 16Mhz; Crystal_SMD_SeikoEpson_FA238-4Pin_3.2x2.5mm

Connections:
D+: J0.A6 (D+), J0.B6 (D+), R0.2
D-: J0.A7 (D-), J0.B7 (D-), R1.2
GND: C0.1, C1.2, C2.2, C3.1, C4.1, C5.2, C6.2, C7.2, C8.2, C9.2, C10.2, J0.A1 (GND), J0.A12 (GND), J0.B1 (GND), J0.B12 (GND), J0.S1 (SHIELD), LED0.3 (VSS), LED1.3 (VSS), LED2.3 (VSS), LED3.3 (VSS), LED4.3 (VSS), LED5.3 (VSS), LED6.3 (VSS), LED7.3 (VSS), LED8.3 (VSS), LED9.3 (VSS), R2.1, R3.1, R4.1, RE0.C, RESET_SW0.C, RESET_SW0.D, U0.5 (UGND), U0.15 (GND), U0.23 (GND), U0.35 (GND), U0.43 (GND), U1.8 (GND), U2.2 (GND), U3.2 (GND), U4.2 (GND), U5.2 (GND), U6.2 (GND), U6.5 (DIR), U7.2 (GND), Y0.2, Y0.4
LED: LED0.4 (DIN), U0.21 (PD3)
MISO: JP0.1 (A), U1.12 (MISO), U7.4 (B)
MISO-H: U0.11 (PB3), U7.3 (A)
MOSI: U1.11 (MOSI), U3.4 (B)
MOSI-H: U0.10 (PB2), U3.3 (A)
MOT-H: U0.20 (PD2), U6.3 (A)
MOTION: U1.9 (MOTION), U6.4 (B)
unnamed: C0.2, U0.17 (XTAL1), Y0.3
unnamed: C1.1, U0.16 (XTAL2), Y0.1
unnamed: C2.1, U0.6 (UCAP)
unnamed: C3.2, C4.2, U1.3 (VDDPIX)
unnamed: D00_00.2 (A), SW00_00.2
unnamed: D00_01.2 (A), SW00_01.2
unnamed: D00_02.2 (A), SW00_02.2
unnamed: D00_03.2 (A), SW00_03.2
unnamed: D00_04.2 (A), SW00_04.2
unnamed: D00_05.2 (A), SW00_05.2
unnamed: D00_06.2 (A), SW00_06.2
unnamed: D01_00.2 (A), SW01_00.2
unnamed: D01_01.2 (A), SW01_01.2
unnamed: D01_02.2 (A), SW01_02.2
unnamed: D01_03.2 (A), SW01_03.2
unnamed: D01_04.2 (A), SW01_04.2
unnamed: D01_05.2 (A), SW01_05.2
unnamed: D01_06.2 (A), SW01_06.2
unnamed: D02_00.2 (A), SWCL_N00.2, SWCL_S00.2
unnamed: D02_01.2 (A), SW02_01.2
unnamed: D02_02.2 (A), SW02_02.2
unnamed: D02_03.2 (A), SW02_03.2
unnamed: D02_04.2 (A), SW02_04.2
unnamed: D02_05.2 (A), SW02_05.2
unnamed: D02_06.2 (A), SW02_06.2
unnamed: D03_00.2 (A), SW03_00.2
unnamed: D03_01.2 (A), SWLS_L01.2, SWLS_S01.2
unnamed: D03_02.2 (A), SW03_02.2
unnamed: D03_03.2 (A), SW03_03.2
unnamed: D03_04.2 (A), SW03_04.2
unnamed: D03_05.2 (A), SW03_05.2
unnamed: D03_06.2 (A), SW03_06.2
unnamed: D04_00.2 (A), SW04_00.2
unnamed: D04_01.2 (A), SW04_01.2
unnamed: D04_02.2 (A), SW04_02.2
unnamed: D04_03.2 (A), SW04_03.2
unnamed: D04_04.2 (A), SWSP_L04.2, SWSP_S04.2
unnamed: D04_05.2 (A), SW04_05.2
unnamed: D04_06.2 (A), SW04_06.2
unnamed: D05_00.2 (A), SWBS_L00.2, SWBS_S00.2
unnamed: D05_01.2 (A), SW05_01.2
unnamed: D05_02.2 (A), SW05_02.2
unnamed: D05_03.2 (A), SW05_03.2
unnamed: D05_04.2 (A), SW05_04.2
unnamed: D05_05.2 (A), SW05_05.2
unnamed: D05_06.2 (A), SW05_06.2
unnamed: D06_00.2 (A), SW06_00.2
unnamed: D06_01.2 (A), SW06_01.2
unnamed: D06_02.2 (A), SW06_02.2
unnamed: D06_03.2 (A), SW06_03.2
unnamed: D06_04.2 (A), SW06_04.2
unnamed: D06_05.2 (A), SW06_05.2
unnamed: D06_06.2 (A), SW06_06.2
unnamed: D07_00.2 (A), SWET_AN00.2, SWET_IS00.2
unnamed: D07_01.2 (A), SW07_01.2
unnamed: D07_02.2 (A), SW07_02.2
unnamed: D07_03.2 (A), SW07_03.2
unnamed: D07_04.2 (A), SW07_04.2
unnamed: D07_05.2 (A), SW07_05.2
unnamed: D07_06.2 (A), SW07_06.2
unnamed: D08_00.2 (A), SW08_00.2
unnamed: D08_01.2 (A), SWRS_L01.2, SWRS_S01.2
unnamed: D08_02.2 (A), SW08_02.2
unnamed: D08_03.2 (A), SW08_03.2
unnamed: D08_04.2 (A), SW08_04.2
unnamed: D08_05.2 (A), SW08_05.2
unnamed: D08_06.2 (A), SW08_06.2
unnamed: D09_00.2 (A), SW09_00.2
unnamed: D09_01.2 (A), SW09_01.2
unnamed: D09_02.2 (A), SW09_02.2
unnamed: D09_03.2 (A), SW09_03.2
unnamed: D09_04.2 (A), SW09_04.2
unnamed: D09_05.2 (A), SW09_05.2
unnamed: D09_06.2 (A), SW09_06.2
unnamed: J0.A5 (CC1), R3.2
unnamed: J0.B5 (CC2), R4.2
unnamed: JP0.2 (B), R7.2
unnamed: LED0.2 (DOUT), LED1.4 (DIN)
unnamed: LED1.2 (DOUT), LED2.4 (DIN)
unnamed: LED2.2 (DOUT), LED3.4 (DIN)
unnamed: LED3.2 (DOUT), LED4.4 (DIN)
unnamed: LED4.2 (DOUT), LED5.4 (DIN)
unnamed: LED5.2 (DOUT), LED6.4 (DIN)
unnamed: LED6.2 (DOUT), LED7.4 (DIN)
unnamed: LED7.2 (DOUT), LED8.4 (DIN)
unnamed: LED8.2 (DOUT), LED9.4 (DIN)
unnamed: R0.1, U0.4 (D+)
unnamed: R1.1, U0.3 (D-)
unnamed: R2.2, U0.33 (~HWB/PE2)
unnamed: R5.1, U1.7 (NRESET)
unnamed: R6.2, U1.15 (LED_P)
RESET: R8.2, RESET_SW0.A, RESET_SW0.B, U0.13 (~RESET)
RE_A: RE0.A, U0.12 (PB7)
RE_B: RE0.B, U0.1 (PE6)
SCLK: U1.10 (SCLK), U4.4 (B)
SCLK-H: U0.9 (PB1), U4.3 (A)
SS: U1.13 (NCS), U5.4 (B)
SS-H: U0.8 (PB0), U5.3 (A), U7.5 (DIR)
VCC: C6.1, C7.1, C8.1, C9.1, C10.1, J0.A4 (VBUS), J0.A9 (VBUS), J0.B4 (VBUS), J0.B9 (VBUS), LED0.1 (VDD), LED1.1 (VDD), LED2.1 (VDD), LED3.1 (VDD), LED4.1 (VDD), LED5.1 (VDD), LED6.1 (VDD), LED7.1 (VDD), LED8.1 (VDD), LED9.1 (VDD), R8.1, U0.2 (UVCC), U0.7 (VBUS), U0.14 (VCC), U0.24 (AVCC), U0.34 (VCC), U0.44 (AVCC), U2.1 (IN), U2.3 (EN), U3.1 (VCC(A)), U3.5 (DIR), U4.1 (VCC(A)), U4.5 (DIR), U5.1 (VCC(A)), U5.5 (DIR), U6.1 (VCC(A)), U7.1 (VCC(A))
VDD: C5.1, R5.2, R6.1, R7.1, U1.4 (VDD), U1.5 (VDDIO), U2.5 (OUT), U3.6 (VCC(B)), U4.6 (VCC(B)), U5.6 (VCC(B)), U6.6 (VCC(B)), U7.6 (VCC(B))
col00: SW00_00.1, SW01_00.1, SW03_00.1, SW04_00.1, SW06_00.1, SW08_00.1, SW09_00.1, SWBS_L00.1, SWBS_S00.1, SWCL_N00.1, SWCL_S00.1, SWET_AN00.1, SWET_IS00.1, U0.41 (PF0)
col01: SW00_01.1, SW01_01.1, SW02_01.1, SW04_01.1, SW05_01.1, SW06_01.1, SW07_01.1, SW09_01.1, SWLS_L01.1, SWLS_S01.1, SWRS_L01.1, SWRS_S01.1, U0.40 (PF1)
col02: SW00_02.1, SW01_02.1, SW02_02.1, SW03_02.1, SW04_02.1, SW05_02.1, SW06_02.1, SW07_02.1, SW08_02.1, SW09_02.1, U0.39 (PF4)
col03: SW00_03.1, SW01_03.1, SW02_03.1, SW03_03.1, SW04_03.1, SW05_03.1, SW06_03.1, SW07_03.1, SW08_03.1, SW09_03.1, U0.38 (PF5)
col04: SW00_04.1, SW01_04.1, SW02_04.1, SW03_04.1, SW05_04.1, SW06_04.1, SW07_04.1, SW08_04.1, SW09_04.1, SWSP_L04.1, SWSP_S04.1, U0.37 (PF6)
col05: SW00_05.1, SW01_05.1, SW02_05.1, SW03_05.1, SW04_05.1, SW05_05.1, SW06_05.1, SW07_05.1, SW08_05.1, SW09_05.1, U0.36 (PF7)
col06: SW00_06.1, SW01_06.1, SW02_06.1, SW03_06.1, SW04_06.1, SW05_06.1, SW06_06.1, SW07_06.1, SW08_06.1, SW09_06.1, U0.32 (PC7)
row00: D00_00.1 (K), D00_01.1 (K), D00_02.1 (K), D00_03.1 (K), D00_04.1 (K), D00_05.1 (K), D00_06.1 (K), U0.30 (PB6)
row01: D01_00.1 (K), D01_01.1 (K), D01_02.1 (K), D01_03.1 (K), D01_04.1 (K), D01_05.1 (K), D01_06.1 (K), U0.28 (PB4)
row02: D02_00.1 (K), D02_01.1 (K), D02_02.1 (K), D02_03.1 (K), D02_04.1 (K), D02_05.1 (K), D02_06.1 (K), U0.26 (PD6)
row03: D03_00.1 (K), D03_01.1 (K), D03_02.1 (K), D03_03.1 (K), D03_04.1 (K), D03_05.1 (K), D03_06.1 (K), U0.22 (PD5)
row04: D04_00.1 (K), D04_01.1 (K), D04_02.1 (K), D04_03.1 (K), D04_04.1 (K), D04_05.1 (K), D04_06.1 (K), U0.19 (PD1)
row05: D05_00.1 (K), D05_01.1 (K), D05_02.1 (K), D05_03.1 (K), D05_04.1 (K), D05_05.1 (K), D05_06.1 (K), U0.31 (PC6)
row06: D06_00.1 (K), D06_01.1 (K), D06_02.1 (K), D06_03.1 (K), D06_04.1 (K), D06_05.1 (K), D06_06.1 (K), U0.29 (PB5)
row07: D07_00.1 (K), D07_01.1 (K), D07_02.1 (K), D07_03.1 (K), D07_04.1 (K), D07_05.1 (K), D07_06.1 (K), U0.27 (PD7)
row08: D08_00.1 (K), D08_01.1 (K), D08_02.1 (K), D08_03.1 (K), D08_04.1 (K), D08_05.1 (K), D08_06.1 (K), U0.25 (PD4)
row09: D09_00.1 (K), D09_01.1 (K), D09_02.1 (K), D09_03.1 (K), D09_04.1 (K), D09_05.1 (K), D09_06.1 (K), U0.18 (PD0)

Board: 2 copper layers, 189 parts (0 on the bottom side), 127 nets, no tracks yet.

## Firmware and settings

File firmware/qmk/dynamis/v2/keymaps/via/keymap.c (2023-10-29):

/* Copyright 2023 bbrfkr
 *
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
 * You should have received a copy of the GNU General Public License
 * along with this program.  If not, see <http://www.gnu.org/licenses/>.
 */

#include QMK_KEYBOARD_H

enum layer_names {
    _QWERTY,
    _LOWER,
    _RAISE,
    _SETTINGS,
};

const uint16_t PROGMEM keymaps[][MATRIX_ROWS][MATRIX_COLS] = {

    [_QWERTY] = LAYOUT_ansi(
        KC_GRV,  KC_1,    KC_2,    KC_3,    KC_4,    KC_5,    KC_6,    KC_7,    KC_8,    KC_9,    KC_0,    KC_MINS, KC_EQL,  KC_BSPC, KC_DEL,
        KC_TAB,  KC_Q,    KC_W,    KC_E,    KC_R,    KC_T,    KC_Y,    KC_U,    KC_I,    KC_O,    KC_P,    KC_LBRC, KC_RBRC, KC_BSLS,
        KC_CAPS, KC_A,    KC_S,    KC_D,    KC_F,    KC_G,    KC_H,    KC_J,    KC_K,    KC_L,    KC_SCLN, KC_QUOT,          KC_ENT,
        KC_TAB,  KC_LSFT, KC_Z,    KC_X,    KC_C,    KC_V,    KC_B,    KC_N,    KC_M,    KC_COMM, KC_DOT,  KC_SLSH, KC_RSFT, MO(1),            KC_UP,
        KC_LCTL, KC_LALT, MO(1),                     KC_SPC,  KC_SPC,  KC_ENT,                    MO(2),   KC_RALT, KC_RCTL,          KC_LEFT, KC_DOWN, KC_RGHT
    ),

    [_LOWER] = LAYOUT_ansi(
        KC_ESC,  KC_F1,   KC_F2,   KC_F3,   KC_F4,   KC_F5,   KC_F6,   KC_F7,   KC_F8,   KC_F9,   KC_F10,  KC_F11,  KC_F12,  KC_DEL,  KC_TRNS,
        KC_TRNS, KC_TRNS, KC_TRNS, KC_TRNS, KC_TRNS, KC_TRNS, KC_TRNS, KC_TRNS, KC_TRNS, KC_TRNS, KC_TRNS, KC_TRNS, KC_TRNS, KC_TRNS,
        KC_PSCR, KC_TRNS, KC_LSFT, KC_LCTL, KC_TRNS, KC_TRNS, KC_TRNS, KC_TRNS, KC_TRNS, KC_TRNS, KC_TRNS, KC_TRNS,          KC_TRNS,
        KC_TRNS, KC_TRNS, KC_TRNS, KC_BTN2, KC_BTN1, KC_BTN3, KC_TRNS, KC_TRNS, KC_TRNS, KC_TRNS, KC_TRNS, KC_TRNS, KC_TRNS, KC_TRNS,          KC_TRNS,
        KC_TRNS, KC_LGUI, KC_TRNS,                   KC_TRNS, KC_TRNS, KC_TRNS,                   MO(3),   KC_RGUI, KC_TRNS,          KC_TRNS, KC_TRNS, KC_TRNS
    ),

    [_RAISE] = LAYOUT_ansi(
        KC_ESC,  KC_F1,   KC_F2,   KC_F3,   KC_F4,   KC_F5,   KC_F6,   KC_F7,   KC_F8,   KC_F9,   KC_F10,  KC_F11,  KC_F12,  KC_DEL,  KC_TRNS,
        KC_TRNS, KC_TRNS, KC_TRNS, KC_TRNS, KC_TRNS, KC_TRNS, KC_TRNS, KC_TRNS, KC_TRNS, KC_TRNS, KC_TRNS, KC_TRNS, KC_TRNS, KC_TRNS,
        KC_PSCR, KC_TRNS, KC_TRNS, KC_TRNS, KC_TRNS, KC_TRNS, KC_TRNS, KC_TRNS, KC_TRNS, KC_TRNS, KC_TRNS, KC_TRNS,          KC_TRNS,
        KC_TRNS, KC_TRNS, KC_TRNS, KC_TRNS, KC_TRNS, KC_TRNS, KC_TRNS, KC_TRNS, KC_TRNS, KC_TRNS, KC_TRNS, KC_TRNS, KC_TRNS, KC_TRNS,          KC_TRNS,
        KC_TRNS, KC_LGUI, MO(3),                     KC_TRNS, KC_TRNS, KC_TRNS,                   KC_TRNS, KC_RGUI, KC_TRNS,          KC_TRNS, KC_TRNS, KC_MUTE
    ),

    [_SETTINGS] = LAYOUT_ansi(
        QK_BOOT, KC_NO,   KC_NO,   KC_NO,    KC_NO,   KC_NO,   KC_NO,   KC_NO,   KC_NO,   KC_NO,   KC_NO,   KC_NO,   KC_NO,   KC_NO,   KC_NO,
        KC_NO,   KC_NO,   KC_NO,   KC_NO,    KC_NO,   KC_NO,   KC_NO,   KC_NO,   KC_NO,   KC_NO,   KC_NO,   KC_NO,   KC_NO,   KC_NO,
        KC_NO,   KC_NO,   KC_NO,   KC_NO,    KC_NO,   KC_NO,   KC_NO,   KC_NO,   KC_NO,   KC_NO,   KC_NO,   KC_NO,            KC_NO,
        KC_NO,   KC_NO,   KC_NO,   KC_NO,    KC_NO,   KC_NO,   KC_NO,   KC_NO,   KC_NO,   KC_NO,   KC_NO,   KC_NO,   KC_NO,   KC_NO,            KC_NO,
        KC_NO,   KC_NO,   KC_NO,                      KC_NO,   KC_NO,   KC_NO,                     KC_NO,   KC_NO,   KC_NO,            KC_NO,   KC_NO,   KC_NO
    ),
};

#if defined(ENCODER_MAP_ENABLE)
const uint16_t PROGMEM encoder_map[][NUM_ENCODERS][NUM_DIRECTIONS] = {
    [_QWERTY] = { ENCODER_CCW_CW(KC_WH_U, KC_WH_D), },
    [_LOWER] = { ENCODER_CCW_CW(KC_VOLU, KC_VOLD) },
    [_RAISE] = { ENCODER_CCW_CW(RGB_MOD, RGB_RMOD) },
    [_SETTINGS] = { ENCODER_CCW_CW(RGB_HUI, RGB_HUD) },
};
#endif

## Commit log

2022-07-09 initial as features (#1)
    機能として完成した最初のコミット
    [acrylic-case.FCStd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]
2022-07-15 Add docs and logos (#2)
    [dynamis-B_Cu.gbr, dynamis-B_Mask.gbr, dynamis-B_Silkscreen.gbr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]
2022-07-16 mod the thickness of gasket mount weight (#8)
    [gasket-mount-case-bottom-case.stl, gasket-mount-case-weight.stl]
2022-07-17 Revert "mod the thickness of gasket mount weight (#8)" (#9)
    This reverts commit 7079f59b7b411e1b7f8ee4e9c4865372847dab10.
    [gasket-mount-case-bottom-case.stl, gasket-mount-case-weight.stl]
2022-07-17 mod-bottom-case-stl (#10)
    [gasket-mount-case-bottom-case.stl]
2022-07-17 Revert "mod-bottom-case-stl (#10)" (#11)
    This reverts commit dcce82f15c9197485225979a70152f3f4f279621.
    [gasket-mount-case-bottom-case.stl]
2022-07-17 Revert "Revert "mod the thickness of gasket mount weight (#8)" (#9)" (#12)
    This reverts commit 5a923a44f460f610c11262448c813ee0f7480208.
    [gasket-mount-case-bottom-case.stl, gasket-mount-case-weight.stl]
2022-10-14 mod gasket thickness (#21)
    [gasket-mount-case-bottom-case.stl, gasket-mount-case-top-case.stl]
2022-10-15 mod sandwitch bottom case (#23)
    [sandwitch-B_Cu.gbr, sandwitch-B_Mask.gbr, sandwitch-B_Silkscreen.gbr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]
2023-04-27 add fillet to 3dp case (#25)
    [gasket-mount-case-bottom-case.stl, gasket-mount-case-top-base.f3d, gasket-mount-case-top-base.stl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]
2023-10-29 Develop v2 (#27)
    [acrylic-case.FCStd, badges.FCStd, bom.csv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]
2023-11-03 feature: dynamical change cpi of trackball sensor

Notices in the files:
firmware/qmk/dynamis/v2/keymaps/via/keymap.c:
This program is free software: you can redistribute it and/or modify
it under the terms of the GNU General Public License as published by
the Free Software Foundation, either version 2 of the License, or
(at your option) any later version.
